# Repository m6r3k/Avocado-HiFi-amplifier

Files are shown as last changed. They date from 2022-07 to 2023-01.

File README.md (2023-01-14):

# Turntable Amplifier

MC preamplifier + RIAA filter + headphone amplifier based on TPA6120A.    

The project includes simulations of the preamplifier including RIAA filters. For the best match to the RIAA, select the filter elements from the simulations !!!
The power supply is in a separate aluminum box, allowing for arbitrary power supply selection.

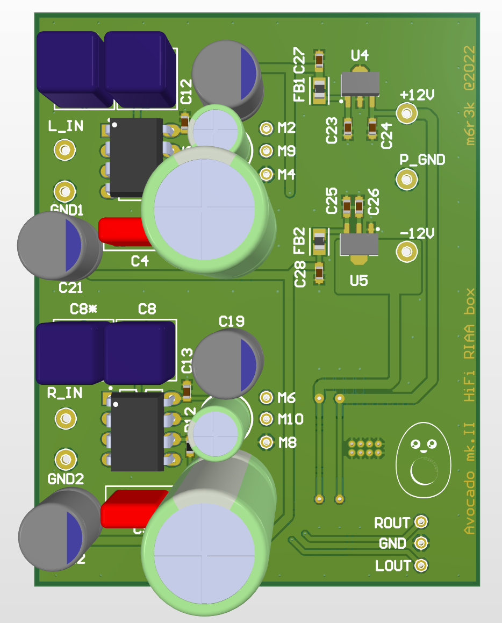
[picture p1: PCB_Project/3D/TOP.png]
TOP

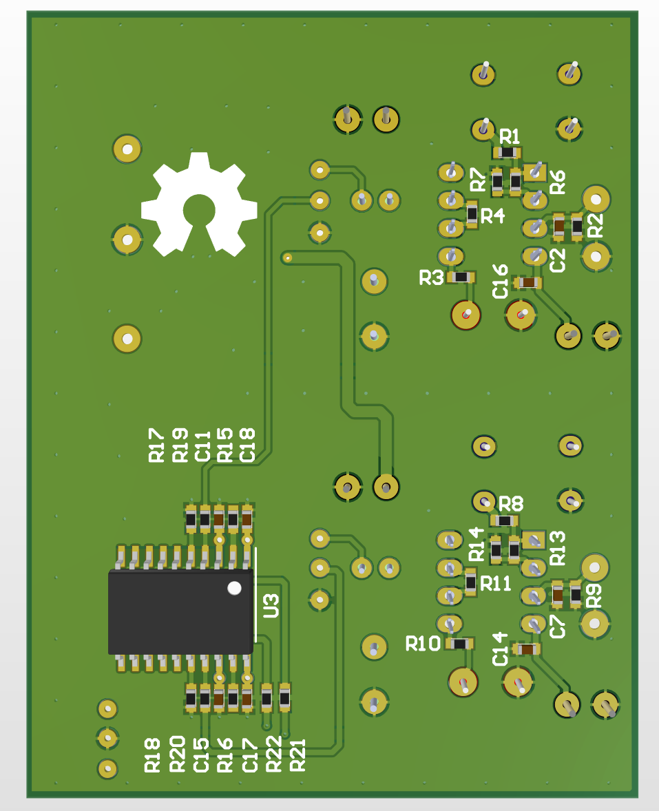
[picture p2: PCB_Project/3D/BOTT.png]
BOTT

## License

GNU General Public License v3.0

**Free project, Hell Yeah!**

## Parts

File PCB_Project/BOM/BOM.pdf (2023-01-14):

Description | Comment | Designator | Quantity | Supplier 1 | Supplier Part Number 1 | Supplier 2 | Supplier Part Number 2
MUSE bipolar capacitor | 10uF | C1, C6 | 2 | Mouser | 647-UES1V100MEM1TD | Digi-Key | 493-10846-1-ND
Ceramic Capacitor NP0 | 120p | C2, C7 | 2 | Mouser | 80-C0603C121F5G | Farnell | 2581047
Foil Capacitor Vishay MKP | 68n | C3, C3*, C8, C8* | 4 | Mouser | 75-MKP1837368011 Farnell | | 2528262
Foil Capacitor WIMA MKS 2 | 100n | C4, C9 | 2 | Mouser | 505-MKS2C031001AJI00
MUSE bipolar capacitor | 100uF | C5, C10 | 2 | Mouser | 647-UES1E101MPM | Digi-Key | 493-15025-ND
Ceramic Capacitor X7R | 100n | C11, C12, C13, C14, C15, C16, C17, C18, C23, C24, C25, C26, C27, C28 | 14 | Mouser | 581-06035C104K4Z2A | Farnell | 1833843
High temp hybrid capacitor -55/125C | 150uF | C19, C20, C21, C22 | 4 | Mouser | 232-35PZE150M8X9 | Digi-Key | 35PZE150M8X9-ND
FERRITE BEAD 120 OHM 0805 1LN | BLM21AG121SN1D | FB1, FB2 | 2 | Farnell | 1515617 | Farnell | 1515617RL
Resistor 1%, 0.1W, 75V | 22K | R1, R8 | 2 | TME | RC0603JR-0722K | Farnell | 9233547
Resistor 1%, 0.1W, 75V | 47K | R2, R9 | 2 | Mouser | 603-AT0603FRE0747KL | Digi-Key | YAG2129CT-ND
Resistor 1%, 0.1W, 75V | 3k16 | R3, R10 | 2 | Mouser | 667-ERJ-PB3B3161V | Digi-Key | P20027CT-ND
Resistor 1%, 0.1W, 75V | 4K7 | R4, R11 | 2 | Mouser | 603-RC0603FR-074K7L | Farnell | 9238565
Resistor 1%, 0.1W, 75V | 220R | R5, R12 | 2 | Mouser | 603-RC0603FR-07220RL | TME | RC0603FR-07220R
Resistor 1%, 0.1W, 75V | 2K | R6, R13, R15, R16, R17, R18 | 6 | Mouser | 603-RC0603FR-072KL | Farnell | 3495801
Resistor 1%, 0.1W, 75V | 100R | R7, R14, R19, R20 | 4 | Mouser | 603-RC0603FR-07100RL | Farnell | 9238360
Resistor 1%, 0.1W, 75V | 10R | R21, R22 | 2 | Mouser | 652-CR0603FX-10R0ELF | Farnell | 2321756
General Purpose Amplifier | NJM4580 | U1, U2 | 2 | Mouser | | | 513-NJM4580D
High Fidelity Stereo Headphone Amplifier, -40 to 85 degC, 20-pin SOP (DWP20), Green (RoHS & no Sb/Br) | TPA6120A2DWPR | U3 | 1 | Mouser | 595-TPA6120A2DWPR | Digi-Key | 296-39339-1-ND
Positive Voltage Regulator, 9V, 4-Pin SOT-89, Tape and Reel | NJM78L09UA-TE1 | U4 | 1
Negative Voltage Regulator, -9V, 4-Pin SOT-89, Tape and Reel | NJM79L09SU3-TE1 | U5 | 1

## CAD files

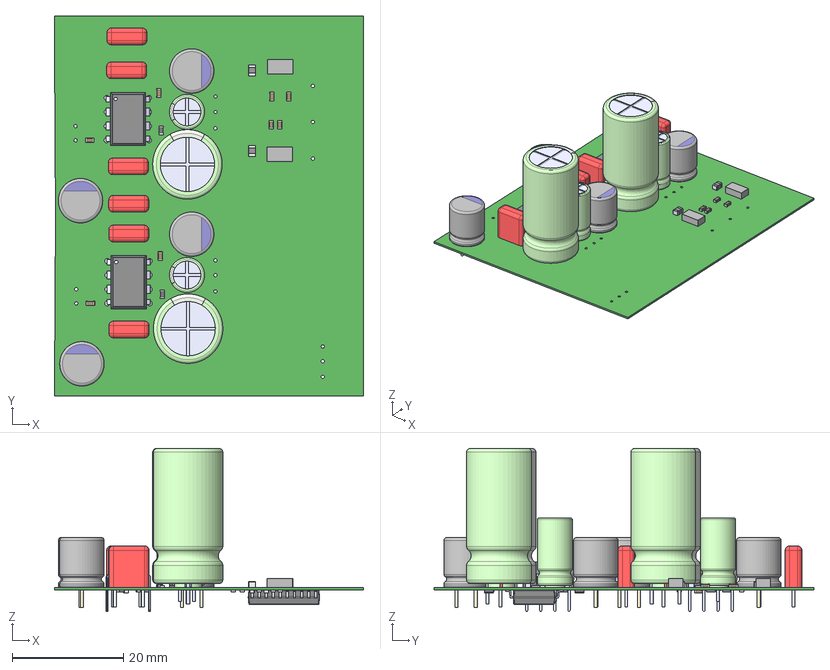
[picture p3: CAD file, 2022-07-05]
PCB_Project/3D/PCB.step
55.6 x 68.3 x 29.3 mm
WIMA_FILM_CAPACITOR_RADIAL_7.2x3.0x7.5_P5.0 x 18
User_Library-res0603-1 x 22
Extruded x 2
Electrodes x 2
Dielectric x 2
Murata x 2
User_Library-cap_0603_lowprofile x 14
PZF8x9 x 4
DWP0020B
DIP8 x 2
UES1E101MPM x 2
UES1V100MEM1TD x 2

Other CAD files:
GalaxyBox/Galaxy_Front_panel.f3d
GalaxyBox/Galaxy_rear_panel.f3d
GalaxyBox/Galaxy_side_panel.f3d
GalaxyBox/Neutrik Rean NYS 367 BK.f3d
GalaxyBox/Neutrik Rean NYS 367 RD.f3d

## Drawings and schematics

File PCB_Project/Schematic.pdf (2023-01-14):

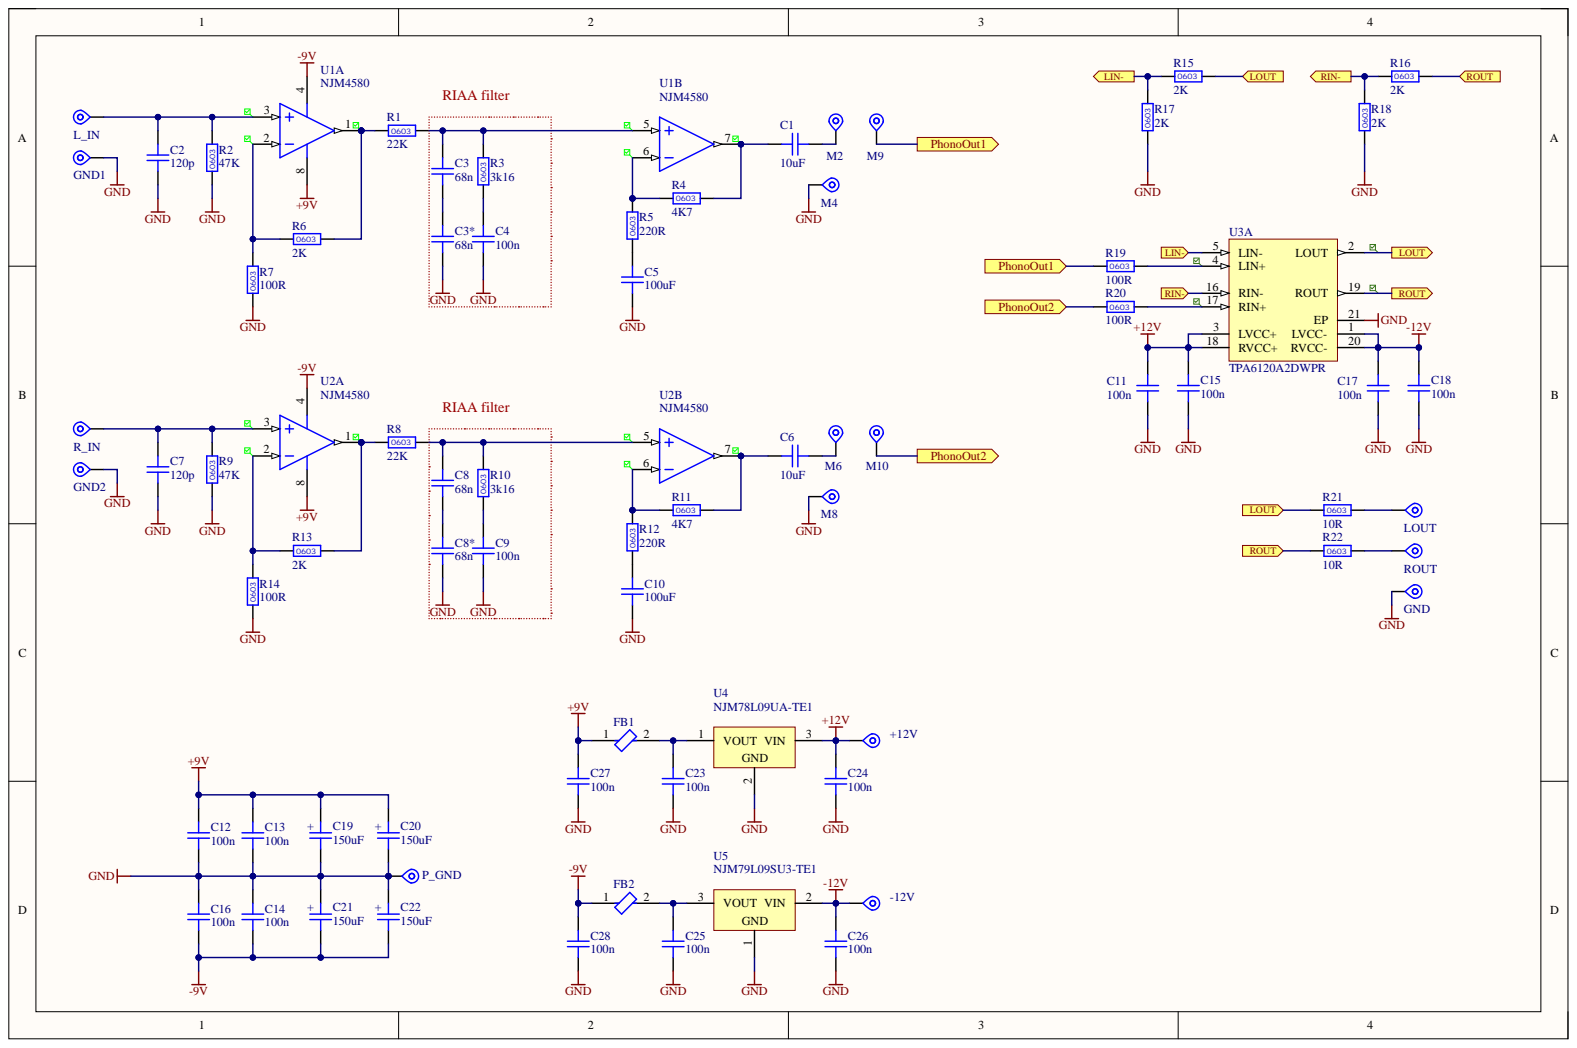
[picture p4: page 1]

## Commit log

2022-05-29 Riaa phono preamplifier
    [PCB.PcbDoc, PreAMP.PrjPcb, Schematic.SchDoc]
2022-06-01 Add 3D models
    [1455K1201.f3d, 1455K1201.igs, 1455K1201.stp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]
2022-06-13 Add new 3D models of PCB components Removed Hamming alu case
    [1455K1201.f3d, 1455K1201.igs, 1455K1201.stp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]
2022-06-18 Add TPA6120
    [PCB.PcbDoc, PreAMP.PrjPcb, Schematic.SchDoc]
2022-06-23 Final PCB
    [PCB.PcbDoc, PreAMP.PrjPcb, Schematic.SchDoc]
2022-06-26 Add 3D models of galaxy case Add BOM
    [Galaxy_Front_panel.f3d, Galaxy_rear_panel.f3d, Galaxy_side_panel.f3d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]
2022-06-26 Add BOM pdf & updated resources
    [PreAMP.PrjPcb, Schematic.SchDoc]
2022-07-05 Add reverse RIAA + new filters
2022-07-05 Updated RIAA filter
    [PCB.PcbDoc, PCB.step, PreAMP.PrjPcb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]
2022-07-21 Modified pads size, add new board name
    [PCB.PcbDoc, PreAMP.PrjPcb, Schematic.SchDoc]
2022-07-21 new BOM.pdf
    [PCB.PcbDoc, Schematic.SchDoc]
2022-08-07 Add blocking capacitor to power lines +9/-9
    [PCB.PcbDoc, PreAMP.PrjPcb, Schematic.SchDoc]
2023-01-14 Add latest version of schematic and BOM
2023-01-14 Add latest modifications
    [PreAMP.PrjPcb]
2023-01-14 Add latest PCB renders
    [PreAMP.PrjPcb]
